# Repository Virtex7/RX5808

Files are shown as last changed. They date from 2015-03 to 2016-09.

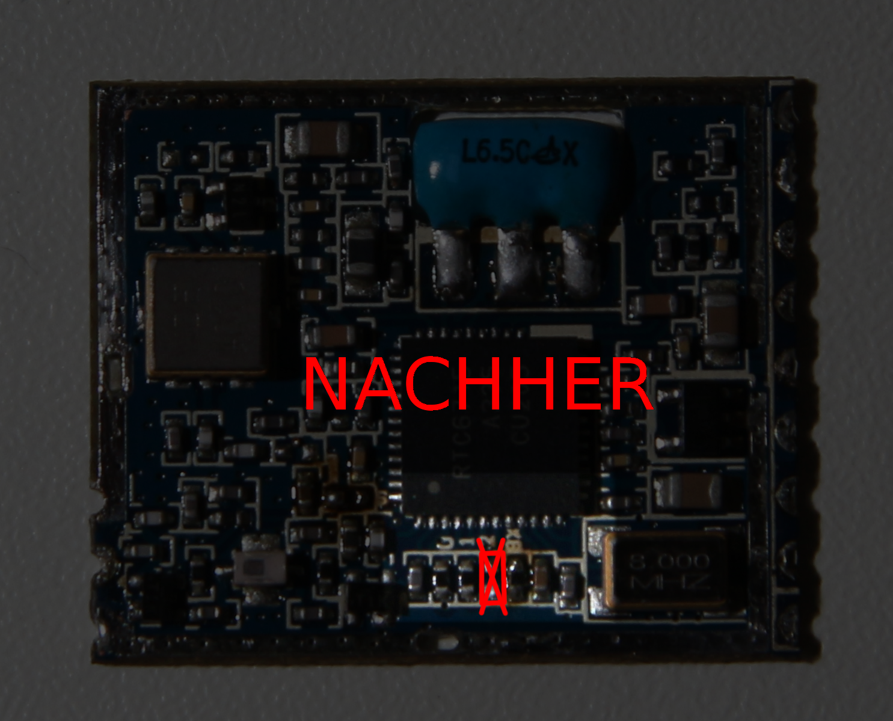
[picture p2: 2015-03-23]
doku/SPI_mod_nachher.png

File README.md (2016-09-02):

# RX5808
FPV Empfänger mit OSD auf OLED, Diversitysupport und vielem mehr.

Software basierend auf dem Projekt von Marko Hoepken
https://code.google.com/p/rx5808-pro/wiki/Overview

sowie inzwischen dem Code des rx5808-pro-diversity von hier:
https://github.com/sheaivey/rx5808-pro-diversity

Es wurden diese Platinen entworfen, um einen vielseitigen FPV-Empfänger bauen zu können

Diese Doku beschränkt sich auf die Hardware, weil die Software schon bei *sheaivey* sehr schön dokumentiert ist.

## Hinweise zur Hardware

Der Hauptgrund für den Bau dieses Moduls ist, dass ich gern ein Modul für die lokale FPV- und Modellbaugruppe designen wollte, das nicht nur die üblichen Funktionen wie freie Kanalwahl, Bandscanner für die Kanalbelegung und übersichtliche Anzeige der Daten hat, sondern auch Diversität unterstützt und allgemein ein schöneres Design hat, als die üblichen Aufbauten. Auch der Schaltwandler direkt auf dem Board hat für eine Bodenstation oder sogar Verwendung direkt an der VR-Brille klare Vorteile.

Dazu kommt, dass ich noch zusätzlich einen HF-Vorverstärker und einen Kopfhöreranschluss verbauen wollte, damit dem Piloten mehr Optionen offen bleiben und das Modul einen Mehrwert gegenüber anderen käuflichen Modulen hat.

Der HF-Verstärker ist auf das 5,8GHz-Band ausgelegt und hat ein Sperrfilter für Signale im 2,4GHz-Band, was im Modellbau heutzutage die Fernsteuerung darstellt. Diese Signale können sonst den Videoempfänger stören und zu Bildstörungen oder sogar dem Totalausfall des Bildes führen, was für die FPV-Piloten fatal ist.

Achtung: HF-Verstärker und Tonausgabe stehen nur bei Verwendung des optionalen Diversity-Moduls zur Verfügung! Es wird auch klar empfohlen, an das Diversity-Erweiterungsmodul keine Richtantennen anzuschließen, wenn der Copter mit einem Funkmodul mit über 25mW Ausgangsleistung und/oder einer Richtantenne ausgestattet ist. Solche Antennen gehören erst mal das Haupt-Empfangsmodul, weil sonst die Gefahr besteht, den Videoempfänger zu überlasten und damit das Videobild zu stören.

Das Diversity-Modul wird automatisch erkannt und dann auch im Menü angezeigt. Es muss keine Änderung an der Software vorgenommen werden. Im Diversity-Modus zeigt eine grüne LED an, welches Modul gerade das Videosignal an den Ausgang liefert. Die Umschaltung zwischen den Empfängern erfolgt für das Videobild unsichtbar.

Schließlich lässt sich noch ein kompatibler Videosender durch eine IR-Schnittstelle auf den gewünschten Kanal einstellen, die dazu nötige IR-Sendediode D5 liegt an einer Platinenecke direkt neben der SMA-Buchse.

## Aufbau
Bestellnummern werden nur bei Bauteilen angegeben, die nicht als "Standardbauteil, also wie ein normaler Kondensator oder Widerstand aus der E12-Reihe, bezeichnet werden können. Leider reicht es nicht aus, ausschließlich bei Digikey zu bestellen, da hier einzelne Teile nicht verfügbar sind. Es gibt in Deutschland keinen Distributor, der alle benötigten Teile liefern kann.

### Bill of Material
| Anzahl | Bauteilname | Gehäuseform | Referenz(en) auf der Platine | Digikeynummer |
| --- | --- | --- | --- | --- |
|

### Platinenlayouts und Löten
Die Platine sind mit KiCAD, einer Version >> 4.0 erstellt und müssen auch damit exportiert werden. Generelle Tips dazu kann ich nicht geben, da es viel zu ausführlich werden würde. Ich empfehle jedoch nicht, für einen Nachbau die Daten direkt zu verwenden, die im Gerber-Verzeichnis sind, sondern stets selbst Fertigungsdaten zu exportieren.

Durch die vielen SMD-Bauteile und vor allem das HF-Filter auf der Diversityplatine bietet sich Reflowlöten klar an. Die Lötpaste kann mittels Dispenser oder auch durch Rakeln aufgebracht werden, wobei ein besonderes Augenmerk auf den kleinen Bauteilen **TPS62160** und **LP38798** gelegt werden sollte. Diese haben ein recht feines Pinraster und kleine Pads, was leicht dazu führen kann, dass die falsche Menge Lötpaste aufgetragen wird.

Von der Reihenfolge her sollte man zuerst die kleinen, meist passiven, Bauelemente auflöten und dann mit den ICs und ggf. Steckern weitermachen. So stehen sich die Bauteile nicht beim Bestücken gegenseitig im Weg herum. Achtung! vor dem Programmieren des Bootloaders **DARF** das OLED noch **NICHT** eingelötet sein, weil man sonst nicht mehr an den Atmel herankäme.

### Test
Bevor das Modul programmiert werden kann, muss es getestet werden. Es geht hier ausschließlich darum, ob der Schaltwandler die richtige Ausgangsspannung liefert. Achtung: nur wenn R21 gesetzt ist, kann der Schaltwandler korrekt arbeiten. Ansonsten gibt er eine leicht zu hohe Spannung aus, weil die Ausgangslast zu gering ist.

Achtung bei der Montage des Kabels zwischen Hauptmodul und Diversityplatine! Die Verpolschutznasen der Micromatchstecker brechen leicht ab und die Diversityplatine ist nicht explizit verpolgeschützt. Daher vor Einschalten der Stromversorgung auf jeden Fall auf korrekte Verkabelung kontrollieren. Beim Verpolen wird zwar die 5V-Versorgung des Moduls auf einen absichtlich nicht verwendeten Pin gelegt, aber durch die Steuersignale könnte dennoch ein Latch-Up-Effekt auftreten.

Die Eingangsspannung wird an den JST-XH-Stecker mit vier Pins angeschlossen, so lange keine Betriebsspannung in den Videoausgang eingespeist wird, ist das Modul verpol- und Überspannungsgeschützt. Sinnvollerweise sollte die Stromversorgung an die beiden oberen Pins des Steckers (Modul liegt so auf dem Tisch, dass der Versorgungsstecker *P1* links liegt) Pin 1 des Steckers ist Power-Masse und Pin 2 Stromversorgung. Für den Test wird hier eine Spannung von 6V eingespeist, weil diese den Mikrocontroller nicht schädigt, wenn der Schaltwandler noch nicht funktioniert, aber eigendlich schon auf 5,0V heruntergeregelt werden sollte. Die Ausgangsspannung kann über den Kondensator C10 leicht gemessen werden; wenn sie passt, also im Breich 4,9 bis 5,1V liegt und sich auch bei Variation der Eingangsspannung nicht ändert, darf die Eingangsspannung auf bis zu 15V angehoben werden. Die Stromaufnahme des Moduls muss hier ohne Empfängermodul etwa bei 10mA liegen. Deutlich höhere Stromaufnahme deutet fast immer auf einen Lötfehler hin.

## Inbetriebnahme
Zuerst muss der Bootloader geflasht werden. Dazu ein ISP-Programmiergerät an den Atmel (ATMEGA328P) anschließen und die Arduino/Genduino-IDE starten. Als Board wird der *Arduino Nano* ausgewählt, der Prozessor ist ein *atmega328* Wenn der Programmiervorgang erfolgreich war, blinkt die eine grüne LED des Hauptboardes mit 1Hz Takt und zeigt so an, dass der Bootloader aufgespielt ist und die Fuses korrekt gesetzt sind.

Jetzt darf das OLED eingelötet werden. **Tipp:** es empfiehlt sich, das OLED mit einem kleinen Stückchen doppelseitigem Klebeband vorne auf den JST-PH-5-Stecker zu kleben, da es so fest ist und nach anlöten nicht mehr verrutschen kann.

### Programmieren der Software

Die Software aus dem Submodul *rx5808-pro-diversity* wird in der Arduino-IDE geöffnet. IDE-Version ab 1.6.6 habe ich getestet, es sollten aber auch frühere Versionen funktionieren. Näheres dazu findet man auch in der Doku beim Entwickler der Software.

**Tipp:** in der Datei *settings.h* lässt sich ein CallSign mit bis zu 10 Zeichen, also z.B. der Name des Piloten, einstellen. Es ist weitaus angenehmer, dieses in der Software am PC einzustellen, als es mit dem kleinen Navigation-Switch direkt am Modul einzugeben.

### Bedienung

Die genaue Bedienung des Geräts ist beim Entwickler der Software zu finden, so viel von mir dazu: Der Navigation-Switch lässt sich nach oben und unten kippen sowie eindrücken. Kippen erzeugt die Funktionen *hoch* und *runter*, Drücken ist die Funktion *Menü* oder im Menü dann *bestätigen*

Es empfiehlt sich, das Modul vor dem ersten richtigen Einsatz zu kalibrieren, der genaue Ablauf steht auch hier in der Softwaredoku.

## Abschließende Hinweise
Das Modul kann eingeschrumpft werden. Dabei bitte auf das OLED aufpassen, die Ecken des Displayglases brechen leicht ab und nehmen dann einen Teil des Folienleiters mit, was das Display zerstört. Ich empfehle, vor dem Einschrumpfen eine kleine Menge Klebstoff unter die Displayecken zu geben, damit diese mechanisch fest sind.
Der Programmierstecker an der unteren Kante des Moduls kann verschlossen werden, er wird für den Betrieb nicht benötigt.

Es ist auch möglich, statt des XH-Steckers für Strom und Videosignal ein Servokabel zu verwenden, auch wenn dies von mir klar nicht empfohlen wird, weil so keine Massetrennung zwischen Signal und Videosignal stattfindet und das Servokabel nicht ziegeschützt ist.
Die Belegung ist so gewählt, dass beim Servokabel Rot und Schwarz die Stromversorgung darstellt und die Signalader das Videosignal führt. Für Tests, oder wenn man gerade keinen XH-Stecker da hat, sicher eine gute Möglichkeit.

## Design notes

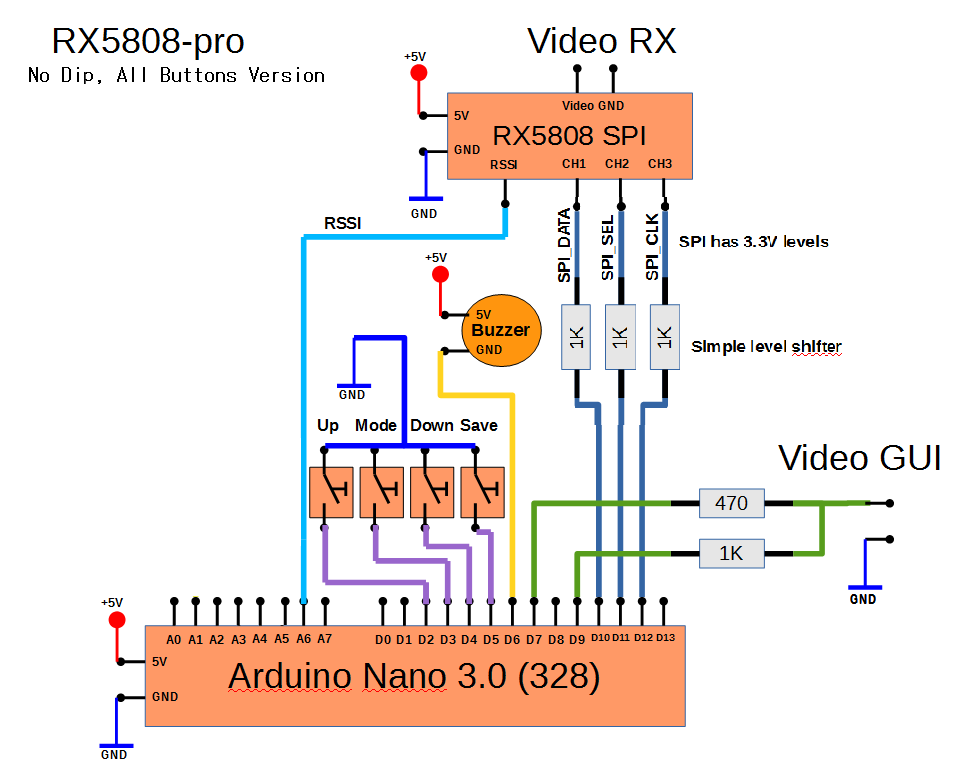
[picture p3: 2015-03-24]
doku/rx5808-pro_schematic_No_DIP.png

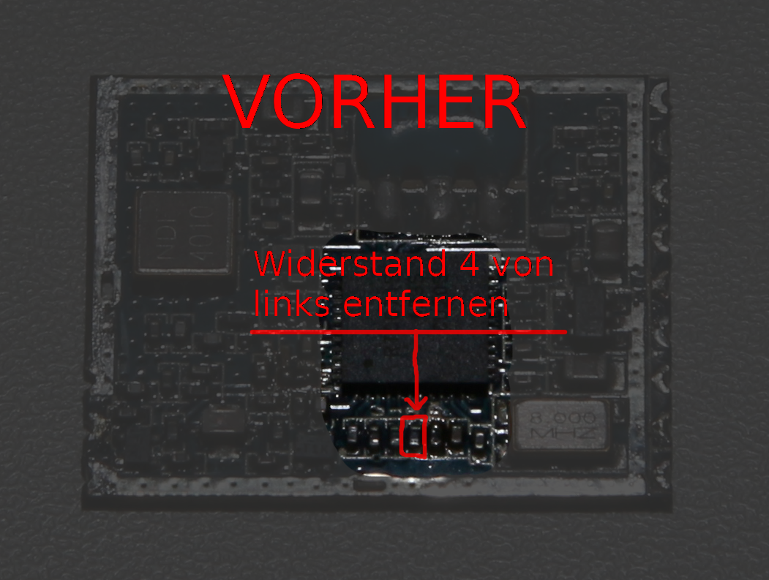
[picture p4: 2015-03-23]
doku/SPI_mod_vorher.png

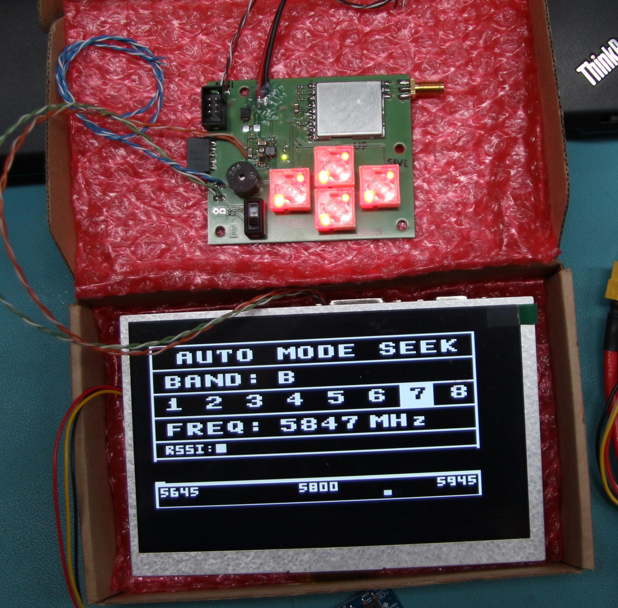
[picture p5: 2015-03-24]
doku/RX5808 groß.jpg

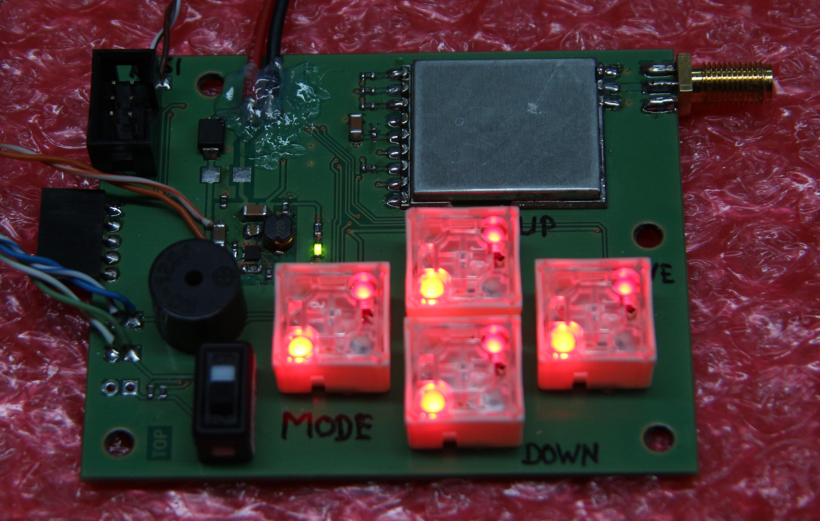
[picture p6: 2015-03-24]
doku/RX5808 Platine.jpg

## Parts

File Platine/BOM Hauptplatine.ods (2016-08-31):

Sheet: main
Reference | Value | Footprint | Anzahl
R20 | 10 | Resistors_SMD:R_0805 | 1
R18 | 100 | Resistors_SMD:R_0603 | 1
R9 | 220 | Resistors_SMD:R_0603 | 2
R12 | 220 | Resistors_SMD:R_0603
R4 | 1k | Resistors_SMD:R_0603 | 9
R5 | 1k | Resistors_SMD:R_0603
R6 | 1k | Resistors_SMD:R_0603
R7 | 1k | Resistors_SMD:R_0603
R13 | 1k | Resistors_SMD:R_0603
R14 | 1k | Resistors_SMD:R_0603
R15 | 1k | Resistors_SMD:R_0603
R17 | 1k | Resistors_SMD:R_0603
R19 | 1k | Resistors_SMD:R_0603
R11 | 1M | Resistors_SMD:R_0603 | 1
L1 | 2,2uH | NR3015:NR3015 | 1
C12 | 4,7u | Capacitors_SMD:C_0805 | 1
R8 | 10k | Resistors_SMD:R_0603 | 1
C5 | 10µ | Capacitors_SMD:C_1206 | 1
R16 | 15k | Resistors_SMD:R_0603 | 1
Y1 | 16 MHz | CSTCE16:CerOsc_3 | 1
C7 | 22µ | Capacitors_SMD:C_1206 | 2
C10 | 22µ | Capacitors_SMD:C_1206
R1 | 100k | Resistors_SMD:R_0603 | 3
R2 | 100k | Resistors_SMD:R_0603
R3 | 100k | Resistors_SMD:R_0603
C1 | 100n | Capacitors_SMD:C_0603 | 10
C2 | 100n | Capacitors_SMD:C_0603
C3 | 100n | Capacitors_SMD:C_0603
C4 | 100n | Capacitors_SMD:C_0603
C6 | 100n | Capacitors_SMD:C_0603
C8 | 100n | Capacitors_SMD:C_0603
C9 | 100n | Capacitors_SMD:C_0603
C11 | 100n | Capacitors_SMD:C_0603
C13 | 100n | Capacitors_SMD:C_0603
C14 | 100n | Capacitors_SMD:C_0603
R22 | 150k | Resistors_SMD:R_0603 | 1
R10 | 680k | Resistors_SMD:R_0603 | 1
IC1 | ATMEGA328-A | Housings_QFP:TQFP-32_7x7mm_Pitch0.8mm | 1
D1 | B 140 F | Diodes_SMD:SMA_Standard | 1
R21 | 0R | Resistors_SMD:R_0603 | 1
SP1 | BUZ | Buzzers_Beepers:Buzzer_12x9.5RM7.6 | 1
P1 | CONN_01X04 | Connectors_JST:JST_XH_S04B-XH-A_04x2.50mm_Angled | 1
P6 | CONN_01X04 | Pin_Headers:Pin_Header_Straight_1x04 | 1
P2 | CONN_01X05 | Connectors_JST:JST_PH_S5B-PH-SM4-TB_05x2.00mm_Angled | 1
P7 | CONN_02X05 | PhilippsFootprints:MICROMATCH-10 | 1
D3 | grün | LEDs:LED_0603 | 2
D4 | grün | LEDs:LED_0603
D5 | IR_EMITTER | LEDs:LED_1206 | 1
U4 | MCPL3-BC-V | PhilippsFootprints:MCPL3-AC-V | 1
D2 | P6SMB 18A SMD | Diodes_SMD:SMB_Standard | 1
U2 | RX5808 | Foxtech:RX5808 | 1
SMA_E1 | SMA_EDGE | PhilippsFootprints:SMA_EDGE_Johnson_142-0701-801 | 1
U3 | sn74lvc1g3157 | TO_SOT_Packages_SMD:SC-70-6 | 1
U1 | TPS62160 | Housings_DFN_QFN:DFN-8-1EP_2x2mm_Pitch0.5mm | 1

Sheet: diversity
Reference | Value | Footprint | Anzahl
R13 | 0 | Resistors_SMD:R_0805 | 1
R10 | 51 | Resistors_SMD:R_0402 | 2
R11 | 51 | Resistors_SMD:R_0402
R1 | 220 | Resistors_SMD:R_0603 | 1
L1 | 1,8nH | Resistors_SMD:R_0402 | 2
L2 | 1,8nH | Capacitors_SMD:C_0402
C3 | 100n | Capacitors_SMD:C_0603 | 3
C13 | 100n | Capacitors_SMD:C_0603
C18 | 100n | Capacitors_SMD:C_0603
C11 | 100µ | Capacitors_SMD:C_1210 | 3
C12 | 100µ | Capacitors_SMD:C_1210
C16 | 100µ | Capacitors_SMD:C_1210
R5 | 10k | Resistors_SMD:R_0603 | 2
R4 | 10k | Resistors_SMD:R_0603
RV1 | 10k lin | PhilippsFootprints:Poti-SMD-Model-23A | 1
C2 | 10n | Capacitors_SMD:C_0603 | 1
C4 | 10u | Capacitors_SMD:C_0805 | 4
C1 | 10u | Capacitors_SMD:C_0805
C5 | 10u | Capacitors_SMD:C_0805
C17 | 10u | Capacitors_SMD:C_0805
R3 | 14k 0 | Resistors_SMD:R_0805 | 1
C10 | 1p | Capacitors_SMD:C_0603 | 2
C9 | 1p | Capacitors_SMD:C_0603
C6 | 1u | Capacitors_SMD:C_0603 | 1
C7 | 1u | Capacitors_SMD:C_0603
C19 | 2,2pF | Capacitors_SMD:C_0402 | 1
R2 | 21k 0 | Resistors_SMD:R_0805 | 1
C15 | 22p | Capacitors_SMD:C_0603 | 1
C8 | 22u | Capacitors_SMD:C_0805 | 1
R12 | 27k | Resistors_SMD:R_0402 | 1
R6 | 3,9k | Resistors_SMD:R_0603 | 2
R7 | 3,9k | Resistors_SMD:R_0603
C14 | 33pF | Capacitors_SMD:C_0603 | 1
R9 | 39k | Resistors_SMD:R_0603 | 2
R8 | 39k | Resistors_SMD:R_0603
Q1 | BFP840 | TO_SOT_Packages_SMD:SOT-143 | 1
P2 | CONN_01X03 | PhilippsFootprints:LUM1503-03 | 1
P1 | CONN_02X05 | PhilippsFootprints:MICROMATCH-10 | 1
IC1 | LP38798 | Housings_DFN_QFN:DFN-12-1EP_4x4mm_Pitch0.5mm | 1
D1 | red | LEDs:LED_0603 | 1
U2 | RX5808 | PhilippsFootprints:RX5808 | 1
SMA_E1 | 931-1175-ND | PhilippsFootprints:SMA_EDGE_Johnson_142-0701-801 | 1 | 2,84
U1 | sn74lvc1g3157 | TO_SOT_Packages_SMD:SC-70-6 | 1
IC2 | TDA1308A | Housings_SOIC:SOIC-8_3.9x4.9mm_Pitch1.27mm | 1

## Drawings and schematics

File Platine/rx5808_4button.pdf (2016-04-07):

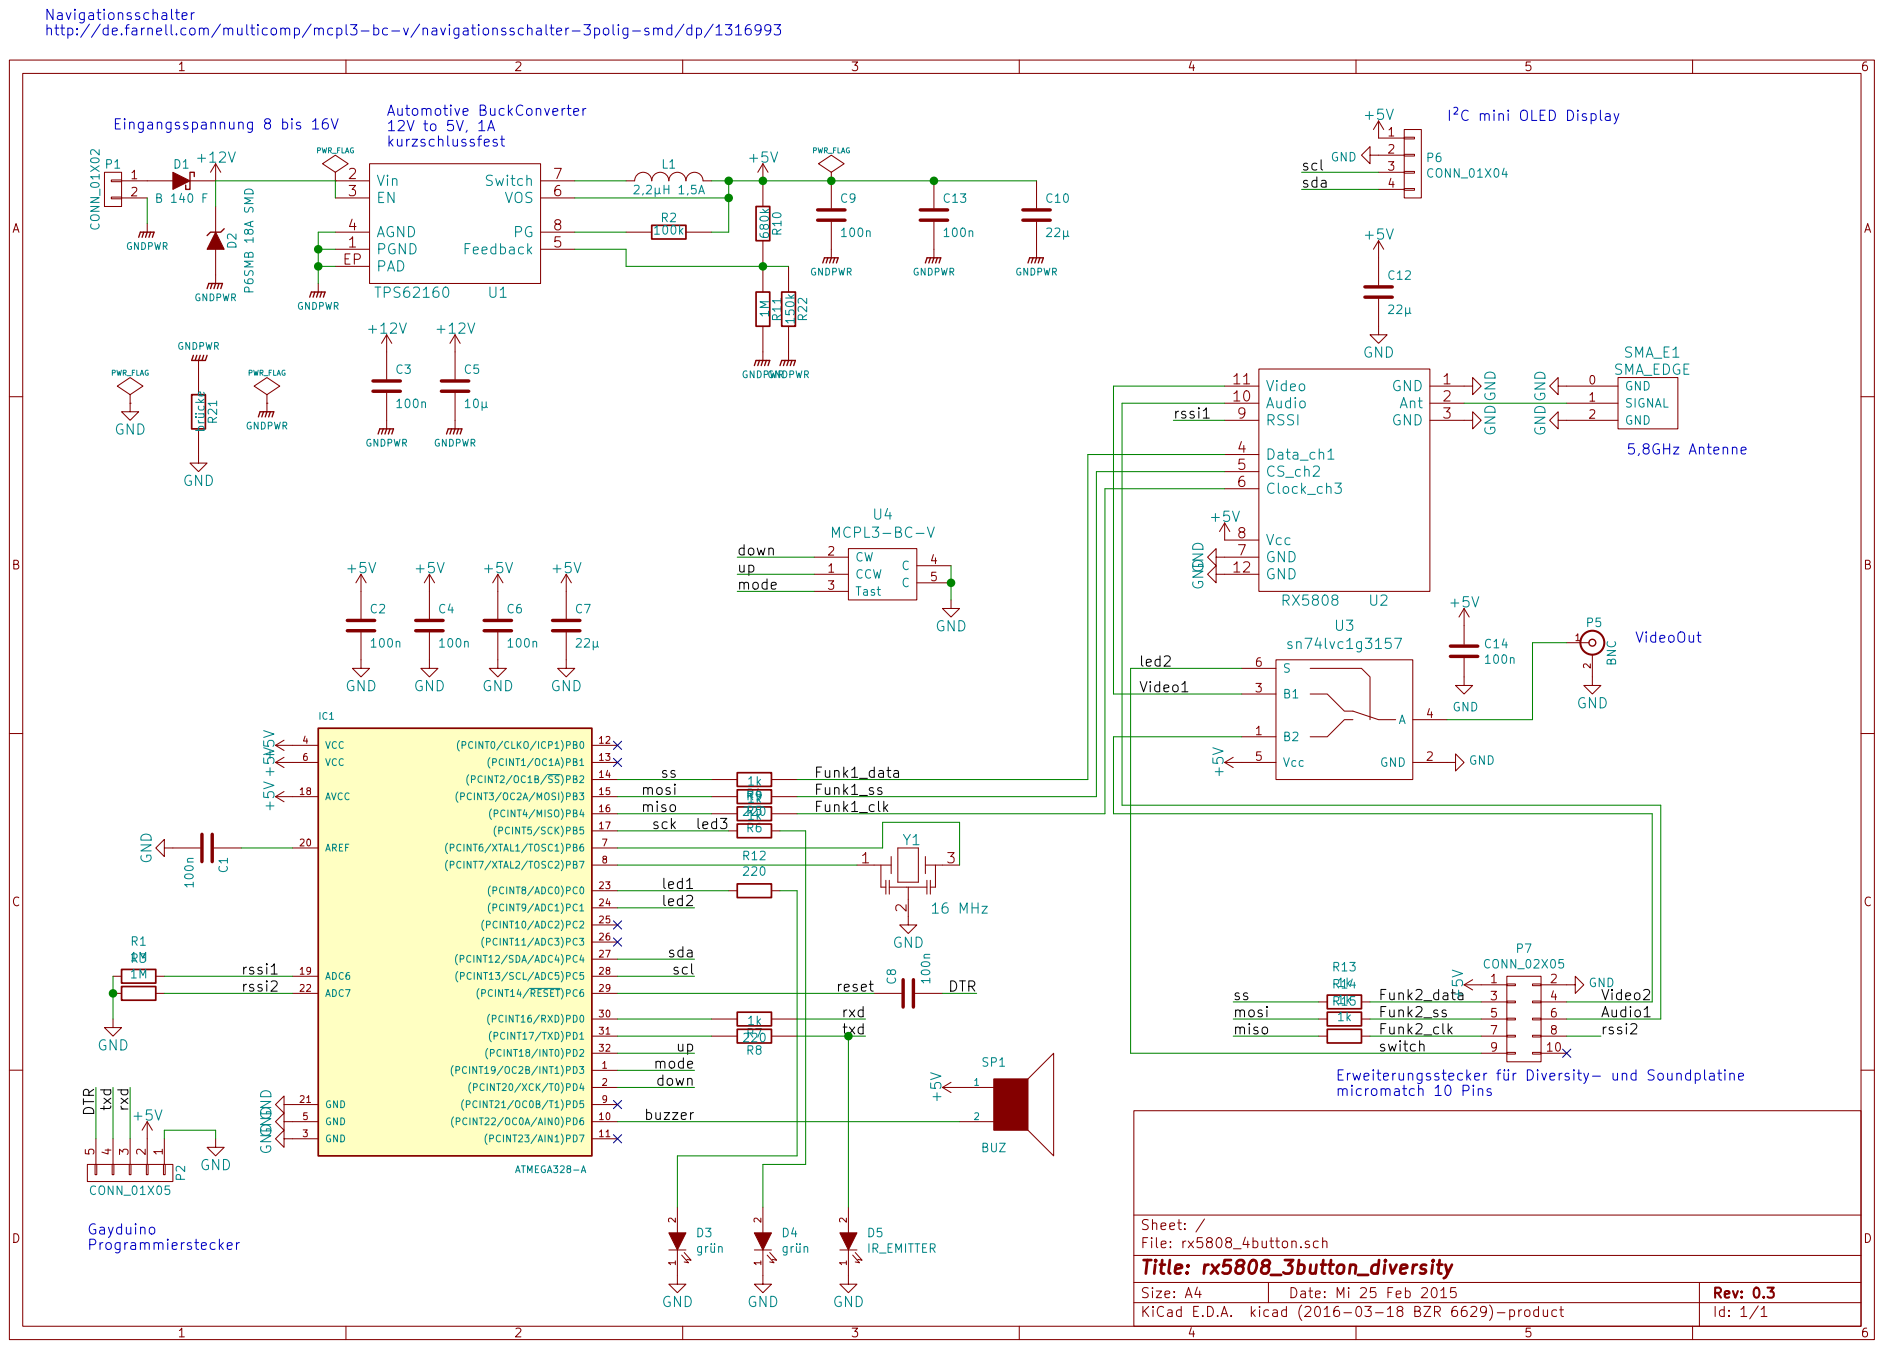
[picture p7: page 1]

I²C mini OLED Display

txd txd rxd DTR

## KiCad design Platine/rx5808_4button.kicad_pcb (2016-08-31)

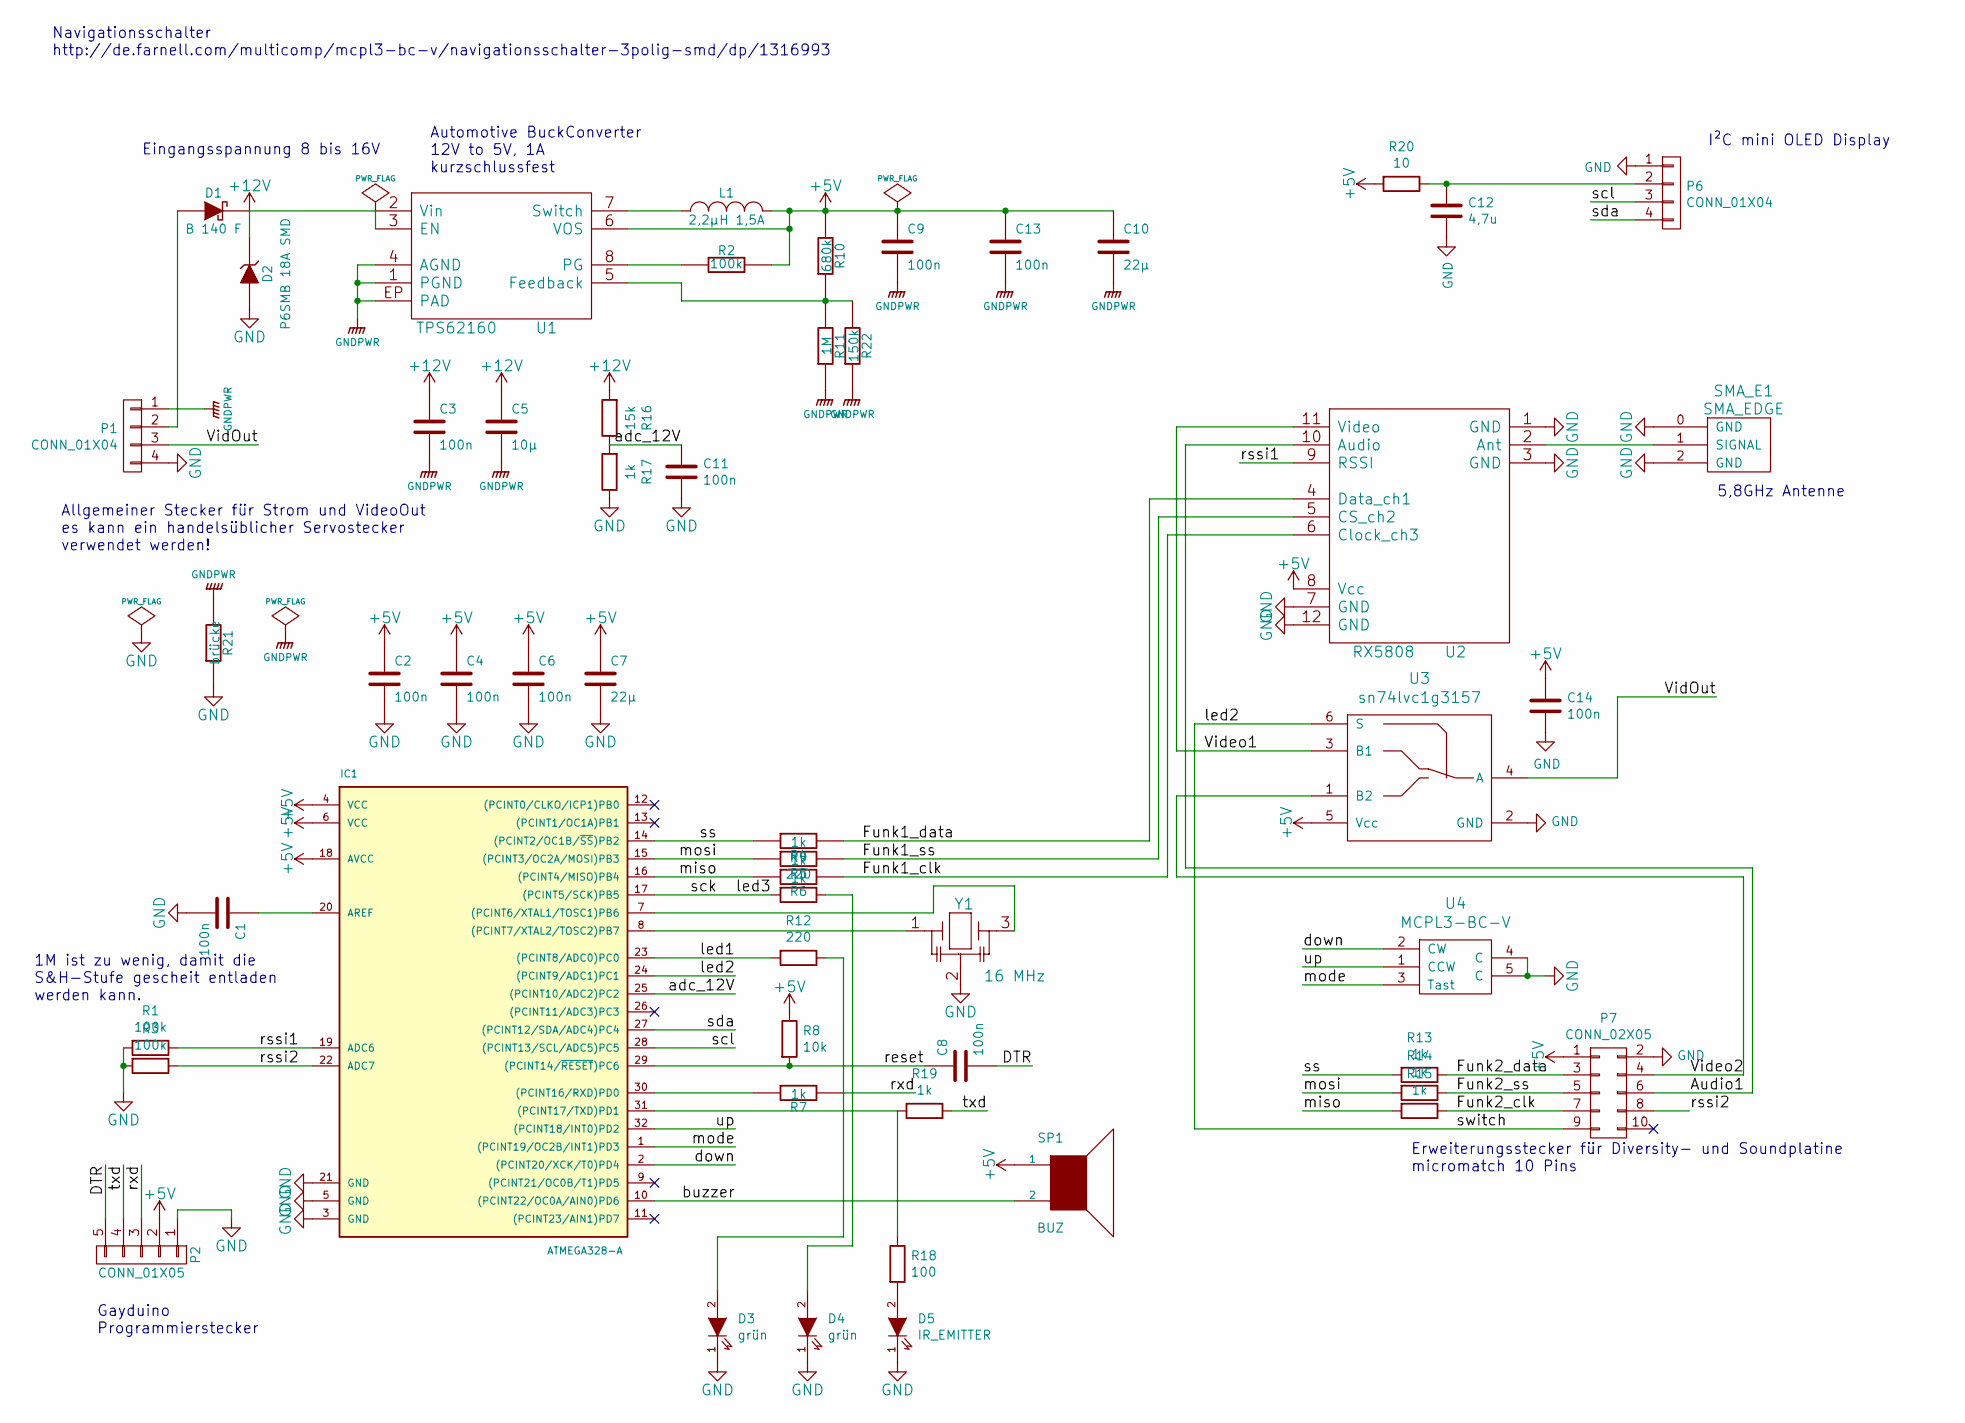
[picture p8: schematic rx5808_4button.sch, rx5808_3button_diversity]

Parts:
C1, C2, C3, C4, C6, C8, C9, C11, C13, C14: 100n; C_0603
C5: 10µ; C_1206
C7, C10: 22µ; C_1206
C12: 4,7u; C_0805
D1: B 140 F; SMA_Standard
D2: P6SMB 18A SMD; SMB_Standard
D3, D4: grün; LED_0603
D5: IR_EMITTER; LED_1206; Digikeynummer 1080-1379-1-ND
IC1: ATMEGA328-A; TQFP-32_7x7mm_Pitch0.8mm
L1: 2,2µH 1,5A; NR3015; Digikeynummer 587-1648-1-ND
P1: CONN_01X04; JST_XH_S04B-XH-A_04x2.50mm_Angled
P2: CONN_01X05; JST_PH_S5B-PH-SM4-TB_05x2.00mm_Angled
P6: CONN_01X04; Pin_Header_Straight_1x04
P7: CONN_02X05; MICROMATCH-10
R1, R2, R3: 100k; R_0603
R4, R5, R6, R7, R13, R14, R15, R17, R19: 1k; R_0603
R8: 10k; R_0603
R9, R12: 220; R_0603
R10: 680k; R_0603
R11: 1M; R_0603
R16: 15k; R_0603
R18: 100; R_0603
R20: 10; R_0805
R21: brücke; R_0603
R22: 150k; R_0603
SMA_E1: SMA_EDGE; SMA_EDGE_Johnson_142-0701-801
SP1: BUZ; Buzzer_12x9.5RM7.6
U1: TPS62160; DFN-8-1EP_2x2mm_Pitch0.5mm
U2: RX5808
U3: sn74lvc1g3157; SC-70-6
U4: MCPL3-BC-V; MCPL3-AC-V
Y1: 16 MHz; CerOsc_3,2x1,3

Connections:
+5V: C2.1, C4.1, C6.1, C7.1, C9.1, C10.1, C13.1, C14.1, IC1.4 (VCC), IC1.6 (VCC), IC1.18 (AVCC), L1.2, P2.2, P7.1, R2.2, R8.1, R10.1, R20.2, SP1.1, U1.6 (VOS), U2.8 (Vcc), U3.5 (Vcc)
+12V: C3.1, C5.1, D1.2 (K), D2.1 (K), R16.2, U1.2 (Vin), U1.3 (EN)
/Audio1: P7.6, U2.10 (Audio)
/DTR: C8.2, P2.5
/Funk1_clk: R6.1, U2.6 (Clock_ch3)
/Funk1_data: R4.1, U2.4 (Data_ch1)
/Funk1_ss: R5.1, U2.5 (CS_ch2)
/Funk2_clk: P7.7, R15.1
/Funk2_data: P7.3, R13.1
/Funk2_ss: P7.5, R14.1
/VidOut: P1.3, U3.4 (A)
/Video1: U2.11 (Video), U3.3 (B1)
/Video2: P7.4, U3.1 (B2)
/adc_12V: C11.1, IC1.25 ((PCINT10/ADC2)PC2), R16.1, R17.2
/buzzer: IC1.10 ((PCINT22/OC0A/AIN0)PD6), SP1.2
/down: IC1.2 ((PCINT20/XCK/T0)PD4), U4.2 (CW)
/led1: IC1.23 ((PCINT8/ADC0)PC0), R12.2
/led2: IC1.24 ((PCINT9/ADC1)PC1), P7.9, U3.6 (S)
/led3: IC1.17 ((PCINT5/SCK)PB5), R9.2
/miso: IC1.16 ((PCINT4/MISO)PB4), R6.2, R15.2
/mode: IC1.1 ((PCINT19/OC2B/INT1)PD3), U4.3 (Tast)
/mosi: IC1.15 ((PCINT3/OC2A/MOSI)PB3), R5.2, R14.2
/reset: C8.1, IC1.29 ((PCINT14/~RESET~)PC6), R8.2
/rssi1: IC1.19 (ADC6), R1.1, U2.9 (RSSI)
/rssi2: IC1.22 (ADC7), P7.8, R3.1
/rxd: P2.3, R7.1
/scl: IC1.28 ((PCINT13/SCL/ADC5)PC5), P6.3
/sda: IC1.27 ((PCINT12/SDA/ADC4)PC4), P6.4
/ss: IC1.14 ((PCINT2/OC1B/~SS~)PB2), R4.2, R13.2
/txd: P2.4, R19.2
/up: IC1.32 ((PCINT18/INT0)PD2), U4.1 (CCW)
GND: C1.2, C2.2, C4.2, C6.2, C7.2, C11.2, C12.2, C14.2, D2.2 (A), D3.1 (K), D4.1 (K), D5.1 (K), IC1.3 (GND), IC1.5 (GND), IC1.21 (GND), P1.4, P2.1, P6.1, P7.2, R1.2, R3.2, R17.1, R21.2, SMA_E1.0 (GND), SMA_E1.2 (GND), U2.1 (GND), U2.3 (GND), U2.7 (GND), U2.12 (GND), U3.2 (GND), U4.4 (C), U4.5 (C), Y1.2
GNDPWR: C3.2, C5.2, C9.2, C10.2, C13.2, P1.1, R11.2, R21.1, R22.2, U1.1 (PGND), U1.4 (AGND), U1.EP (PAD)
unnamed: C1.1, IC1.20 (AREF)
unnamed: C12.1, P6.2, R20.1
unnamed: D1.1 (A), P1.2
unnamed: D3.2 (A), R12.1
unnamed: D4.2 (A), R9.1
unnamed: D5.2 (A), R18.2
unnamed: IC1.7 ((PCINT6/XTAL1/TOSC1)PB6), Y1.3
unnamed: IC1.8 ((PCINT7/XTAL2/TOSC2)PB7), Y1.1
unnamed: IC1.30 ((PCINT16/RXD)PD0), R7.2
unnamed: IC1.31 ((PCINT17/TXD)PD1), R18.1, R19.1
unnamed: L1.1, U1.7 (Switch)
unnamed: R2.1, U1.8 (PG)
unnamed: R10.2, R11.1, R22.1, U1.5 (Feedback)
unnamed: SMA_E1.1 (SIGNAL), U2.2 (Ant)

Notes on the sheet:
Gayduino Programmierstecker
5,8GHz Antenne
Eingangsspannung 8 bis 16V
Automotive BuckConverter 12V to 5V, 1A kurzschlussfest
I²C mini OLED Display
Erweiterungsstecker für Diversity- und Soundplatine micromatch 10 Pins
Navigationsschalter http://de.farnell.com/multicomp/mcpl3-bc-v/navigationsschalter-3polig-smd/dp/1316993
1M ist zu wenig, damit die S&H-Stufe gescheit entladen werden kann.
Allgemeiner Stecker für Strom und VideoOut es kann ein handelsüblicher Servostecker verwendet werden!

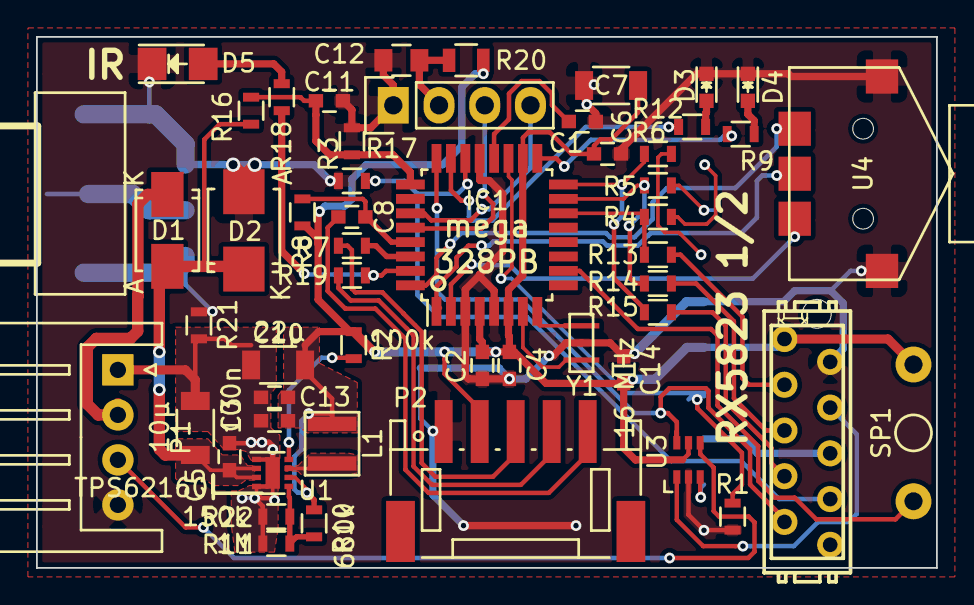
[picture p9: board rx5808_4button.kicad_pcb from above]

Board: 2 copper layers, 50.0 x 29.5 mm, 54 parts (1 on the bottom side), 47 nets.

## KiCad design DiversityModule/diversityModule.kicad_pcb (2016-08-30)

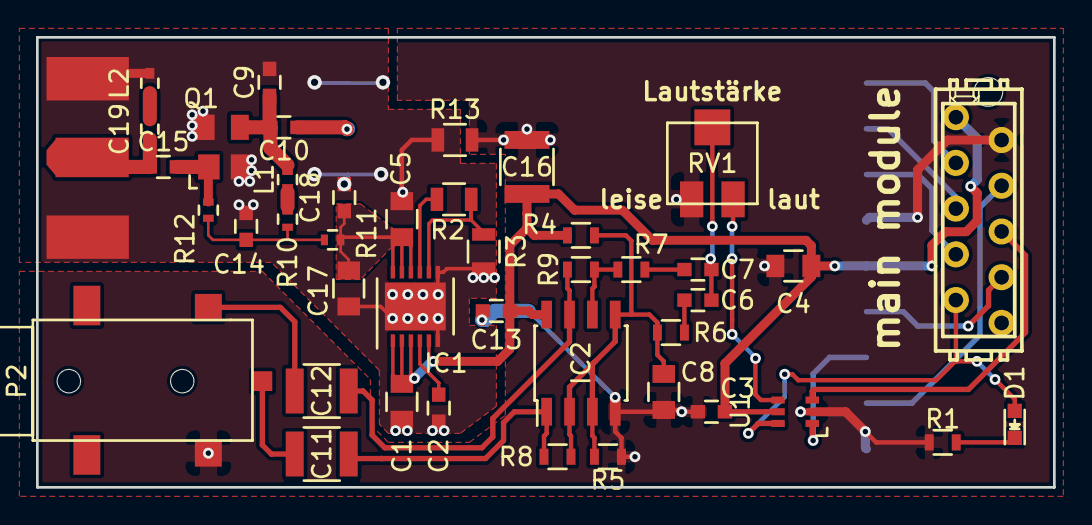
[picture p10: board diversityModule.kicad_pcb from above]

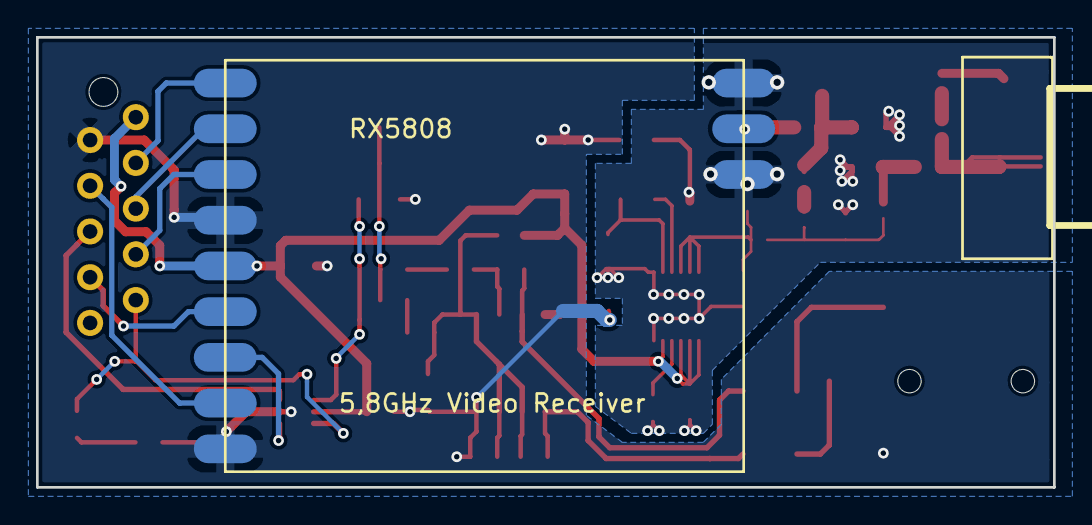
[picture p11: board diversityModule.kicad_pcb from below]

Board: 2 copper layers, 56.5 x 25.0 mm, 44 parts (2 on the bottom side), 33 nets.

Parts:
C1, C4, C5, C17: 10u; C_0805
C2: 10n; C_0603
C3, C13, C18: 100n; C_0603
C6, C7: 1u; C_0603
C8: 22u; C_0805
C9, C10: 1p; C_0603
C11, C12, C16: 100µ; C_1210
C14: 33pF; C_0603
C15: 22p; C_0603
C19: 2,2pF; C_0402
D1: red; LED_0603
IC1: LP38798; DFN-12-1EP_4x4mm_Pitch0.5mm
IC2: TDA1308A; SOIC-8_3.9x4.9mm_Pitch1.27mm
L1: 1,8nH; R_0402
L2: 1,8nH; C_0402
P1: CONN_02X05; MICROMATCH-10
P2: CONN_01X03; LUM1503-03
Q1: BFP840; SOT-143
R1: 220; R_0603
R2: 21k 0,1%; R_0805
R3: 14k 0,1%; R_0805
R4, R5: 10k; R_0603
R6, R7: 3,9k; R_0603
R8, R9: 39k; R_0603
R10, R11: 51; R_0402
R12: 27k; R_0402
R13: 0; R_0805
RV1: POT; Poti-SMD-Model-23A
SMA_E1: SMA_EDGE; SMA_EDGE_Johnson_142-0701-801
U1: sn74lvc1g3157; SC-70-6
U2: RX5808

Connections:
+5V: C1.1, C3.1, C4.1, C13.1, C16.1, IC1.1, IC1.2, IC1.3, IC1.5, IC2.8, P1.1, R4.1, U1.5, U2.8
/+3,0V: C5.1, C17.1, C18.1, IC1.10, IC1.11, IC1.12, R11.2
/audio1: P1.6, U1.3
/clk: P1.7, U2.6
/data: P1.3, U2.4
/rssi: P1.8, U2.9
/ss: P1.5, U2.5
/switch: D1.2, P1.9, U1.6
/video2: P1.4, U2.11
GND: C3.2, C4.2, C8.2, C13.2, C16.2, IC2.4, P1.2, P2.1, R1.2, R5.2, R13.1, RV1.3, U1.2, U2.7, U2.12
GNDA: C1.2, C2.2, C5.2, C9.2, C14.1, C17.2, C18.2, IC1.6, IC1.7, IC1.13, L2.2, Q1.2, Q1.4, R3.2, R13.2, SMA_E1.0, SMA_E1.2, U2.1, U2.3
unnamed: C2.1, IC1.4
unnamed: C6.1, R6.2
unnamed: C6.2, C7.2, RV1.2
unnamed: C7.1, R7.2
unnamed: C8.1, IC2.2, IC2.3, IC2.5, R4.2, R5.1, R6.1, R8.2
unnamed: C9.1, C10.1, L1.2, Q1.3
unnamed: C10.2, U2.2
unnamed: C11.1, IC2.1, R8.1
unnamed: C11.2, P2.2
unnamed: C12.1, IC2.7, R9.1
unnamed: C12.2, P2.3
unnamed: C14.2, R10.1, R11.1, R12.2
unnamed: C15.1, C19.1, SMA_E1.1
unnamed: C15.2, Q1.1, R12.1
unnamed: C19.2, L2.1
unnamed: D1.1, R1.1
unnamed: IC1.8, R2.2, R3.1
unnamed: IC1.9, R2.1
unnamed: IC2.6, R7.1, R9.2
unnamed: L1.1, R10.2
unnamed: RV1.1, U1.4
unnamed: U1.1, U2.10

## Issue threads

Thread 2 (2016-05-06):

IR-LED directly conntected to arduino serial-programmer connector

ep092, 2016-05-06:
The IR-LED is directly connected to the TX wire of the UART used for serial programming. This limits the voltage and is probably the reason for the errors at programming over bootloader.

Virtex7, 2016-05-07:
geändert.
die LED hat jetzt einen eigenen widerstand.
Layout muss noch angepasst werden.

Virtex7, 2016-05-07:
auch im layout gefixt.

Closed 2016-05-07.

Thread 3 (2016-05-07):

Pulldown on RSSI to weak

ep092, 2016-05-07:
The 1MOhm resistor at the RSSI input ist to weak to drive the ADC input. This ist a problem if the slave receiver is not connected. Presumably the sample and hold capacitance of the ADC is not discharged fast enough. -->change to a lower value.

Virtex7, 2016-05-07:
auch geändert.
keine Anpassungen im Layout nötig.

Closed 2016-05-07.

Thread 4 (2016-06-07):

Tonausgabe des Diversitymoduls testen

Virtex7, 2016-06-07:
zu testen sind:

Lautstärke (genug?)
Lautstärkeeinstellung (Bereich ok?)
Passform und Pinbelegung der Klinkenbuchse (Lumberg)

Virtex7, 2016-06-13:
KH-Buchse angepasst, muss aber noch verifiziert werden.

Virtex7, 2016-08-31:
KH-Buchse auf aktueller Releas machanisch passend, elektronisch steht noch auf TODO.

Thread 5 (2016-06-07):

Packages überprüfen

Virtex7, 2016-06-07:
Packages der folgenden Bauteile ändern: (diversity-Platine)

- Videoschalter (sot23-6 auf SC70)
- HF-Transistor auf "das kleinere" Package ändern

Virtex7, 2016-06-07:
der HF-Transistor BFP840FESD ist im TSFP-4-1 (kleiner als sot143)

Virtex7, 2016-06-07:
Videoschalter geändert, HF-Transistor noch nicht.

Virtex7, 2016-06-13:
anderen HF Transistor (BFP840ESD) genommen, der zwar nur noch 80GHz ft hat, aber das reicht auch aus. alle anderen Werte gleich geblieben.

Closed 2016-06-13.

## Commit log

2015-02-26 inital commit nach Ersetellen des Schaltplanes
    [rx5808_4button.sch]
2015-02-26 schaltplan weiter und mehr Footprints erstellt
    [rx5808_4button.sch]
2015-02-27 Footprints für alle Taster und Schalter erstellt, inital commit für Platine
    [rx5808_4button.kicad_pcb, rx5808_4button.sch]
2015-02-27 Layout fertig und Footprint für SMA geaddet.
    [rx5808_4button.kicad_pcb, rx5808_4button.sch]
2015-02-28 andere Spule und neues Layout für den Schaltwandler
    [rx5808_4button.kicad_pcb, rx5808_4button.sch]
2015-02-28 Schaltwandler weiter verbessert
    [rx5808_4button.kicad_pcb]
2015-02-28 finale änderungen an Leiterbahnen
    [rx5808_4button.kicad_pcb]
2015-03-21 rssi-anschluss für externe RSSI-Anzeige dazugebaut
    [rx5808_4button.kicad_pcb, rx5808_4button.sch]
2015-03-23 Bilder für SPI-Mod der neuen Version des Empfängermoduls
2015-03-25 code und TVLIB dem sourcecode geadded, weil die quellen nicht als submodule eingebunden werden können.
2015-04-02 symbol hinzugefügt
    [rx5808_4button.kicad_pcb]
2015-04-04 dickbutt inserted
    [rx5808_4button.kicad_pcb]
2015-04-04 Layout fertig - cinchbuchsen für Video eingebaut.
    [rx5808_4button.kicad_pcb, rx5808_4button.sch]
2015-04-04 SMA-buchse richtig gestellt
    [rx5808_4button.kicad_pcb]
2015-04-04 130k-Ohm durch zwei parallele Widerstände ersetzt, um eine vollständige E12-Kompatibilität gewährleisten zu können
    [rx5808_4button.kicad_pcb, rx5808_4button.sch]
2015-04-04 footprint cinch angepasst (npth löcher gelöscht)
    [rx5808_4button.kicad_pcb]
2015-04-04 letzte Änderungen für Fertigung
    [rx5808_4button.kicad_pcb]
2015-05-20 mehr zeug in die gitignore und etwas Ordnung gemacht.
2015-05-20 Platinendesigndaten in einen extra ordner verschoben
    [rx5808_4button.kicad_pcb, rx5808_4button.sch]
2015-05-26 das neue Immersion RC RaceBand kommt zum Empfänger dazu!
    [rx5808_4button.sch]
2016-04-07 neue LIB für den micromatchstecker
    [rx5808_4button.kicad_pcb, rx5808_4button.sch]
2016-04-07 Footprint für neue spule hinzugefügt
2016-04-07 Platine fertig und exportiert.
    [rx5808_4button.kicad_pcb, rx5808_4button.sch]
2016-04-07 diversity-empfangsmodul schaltplan dazugefügt
    [diversityModule.kicad_pcb, diversityModule.sch]
2016-04-13 Layout fertig. Überprüfung steht aus.
    [diversityModule.kicad_pcb, diversityModule.sch, rx5808_4button.kicad_pcb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]
2016-04-20 BOM für beide platinen des kompletten moduls dazugefügt
    [RX5823 komplett Teile.ods, diversityModule.kicad_pcb, diversityModule.sch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]
2016-04-23 Exports vom neuen Layout
    [rx5808_4button-B.Cu.gbl, rx5808_4button-B.Mask.gbs, rx5808_4button-B.SilkS.gbo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]
2016-05-07 schaltplan und netzliste für die beiden issues geändert.
    [rx5808_4button.sch]
2016-05-07 jetzt auch layout geändert. micromatchbuchse und/oder buzzer sollten noch verschoben werden!
    [rx5808_4button.kicad_pcb, rx5808_4button.sch]
2016-05-24 neue appNote für ein 2,4GHz notchfilter
    [RX5823 komplett Teile.ods]
2016-06-07 fuses-datei für den Atmega328PB dazugefügt, Bootloaderstecker auf JST PH geändert, Filterkondensator und Widerstand für OLED hinzugefügt
    [rx5808_4button.kicad_pcb, rx5808_4button.sch]
2016-06-07 RC-Filter für OLED hinzugefügt und eingelayoutet
    [rx5808_4button.kicad_pcb, rx5808_4button.sch]
2016-06-07 Layoutänderungen für videoumschalter (anderes gehäuse)
    [diversityModule.kicad_pcb, diversityModule.sch]
2016-06-13 Klinkenbuchse ausgetauscht und zur Lib hinzugefügt.
    [diversityModule.kicad_pcb, diversityModule.sch]
2016-06-13 vergessen, das Layout zu speichern.
    [diversityModule.kicad_pcb]
2016-07-08 initial commit outline und pinheader platziert
    [master.kicad_pcb, master.sch]
2016-08-30 BOM hinzugefügt
    [BOM Hauptplatine.ods, diversityModule.kicad_pcb, diversityModule.sch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]
2016-08-31 BOM fertiggestellt und alten Code gelöscht
    [BOM Hauptplatine.ods, rx5808_4button.kicad_pcb, rx5808_4button.sch]
2016-09-01 alten Code gelöscht und README etwas erweitert.
    [RX5823 komplett Teile.ods]
2016-09-02 Hexfile vom alten Code gelöscht und README-md weitergeschrieben
    [rx5808_4button.sch]
